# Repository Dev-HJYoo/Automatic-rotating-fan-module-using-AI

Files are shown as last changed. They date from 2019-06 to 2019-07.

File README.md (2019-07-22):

한글판의 경우 위의 웹사이트에서 확인할 수 있습니다.
#  Automatic rotating fan module using AI
> if you have a fan and install the module, you will use Automatic rotating fan.

**[[Presentation](Presentation)]**

 This project is the 2019 1st Semester Converged Capstone Design Project. 

 We learned AI in the first semester of 2019. we thought to use AI. And, we thought it would be all right if we made a fan to follow people in the hot summer. so, we made Automatic rotating fan module using object detection.

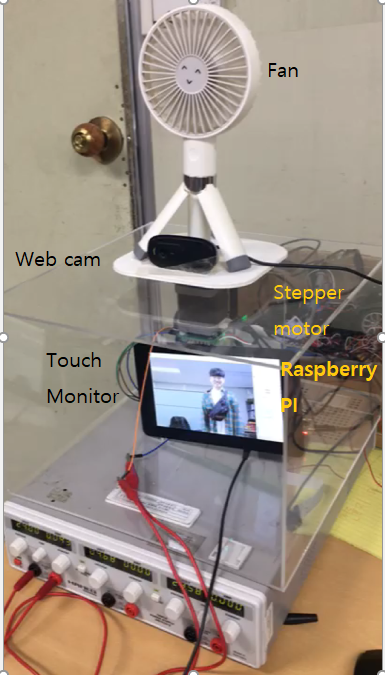
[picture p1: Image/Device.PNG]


Video Label (https://youtu.be/eMBiMkDRgPI?t=0s) 
Video Label (https://youtu.be/c7UqDB0MPdQ?t=0s) 

## Component

Device

- Raspberry pi 3B+
- Stepper Motor
- Touch Monitor
- Web cam
- PC

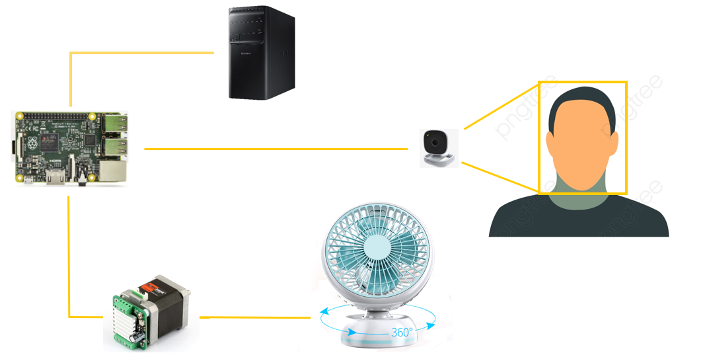
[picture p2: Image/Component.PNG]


## H/W

#### Outline Map
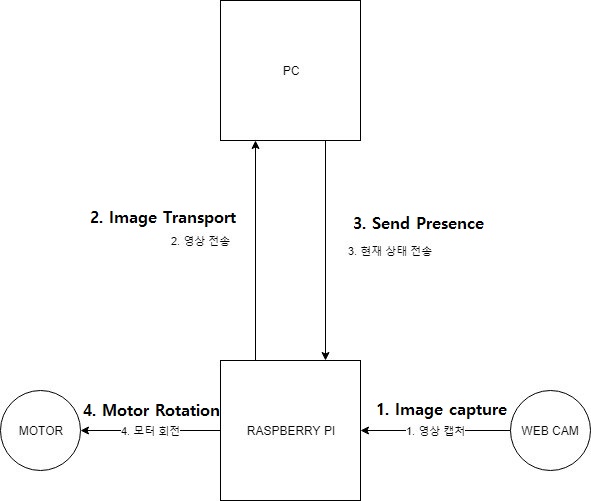
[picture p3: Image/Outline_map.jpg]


#### H/W Circuit

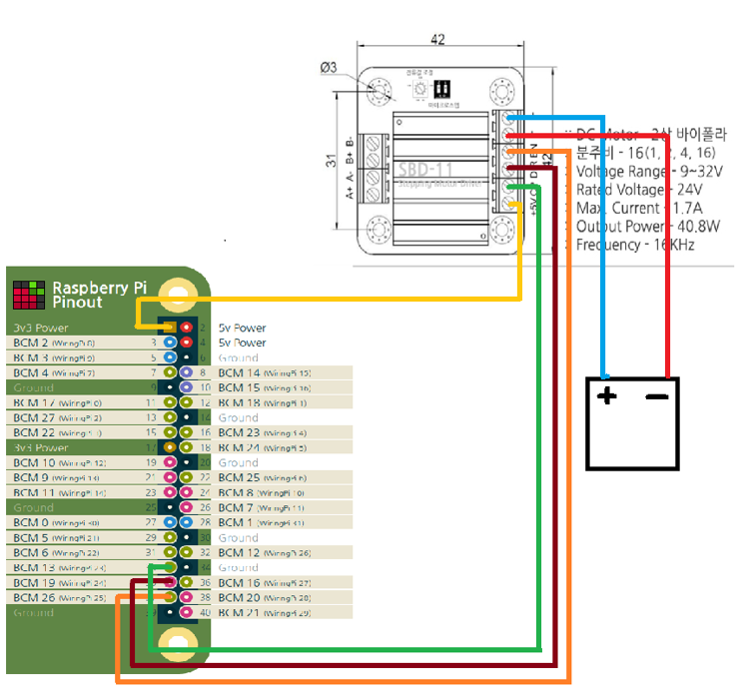
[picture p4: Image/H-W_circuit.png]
 

#### 3D Model
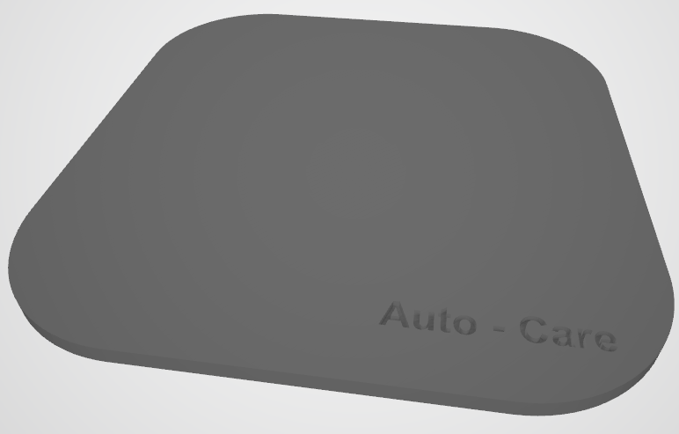
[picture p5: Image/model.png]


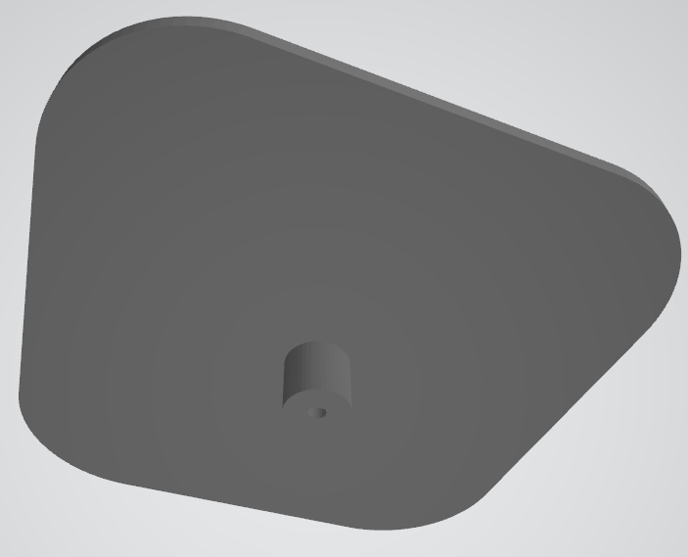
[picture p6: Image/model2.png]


## S/W

#### Object Detection

we used SSD-MobileNet-V1 model because we used Raspberry Pi( single board ). 

#### Algorithm

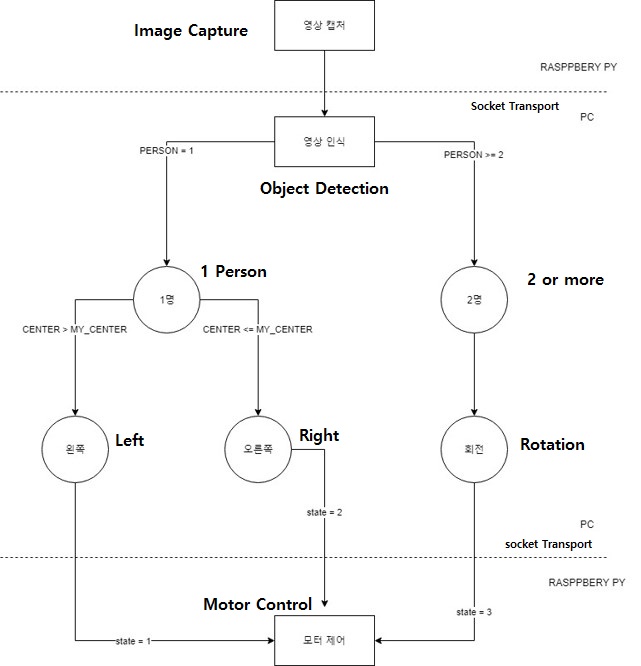
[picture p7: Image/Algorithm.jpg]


#### Socket Transport

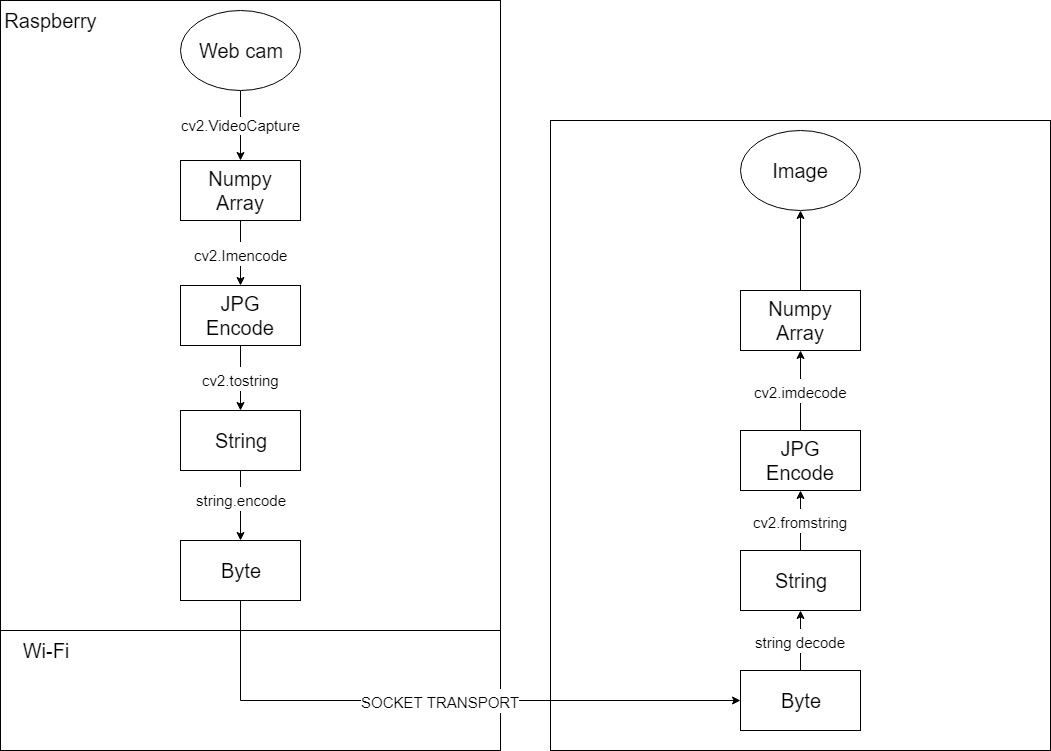
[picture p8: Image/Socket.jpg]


## Object Detection

#### Gather Data

using Capture/capture_from_webcam.py.

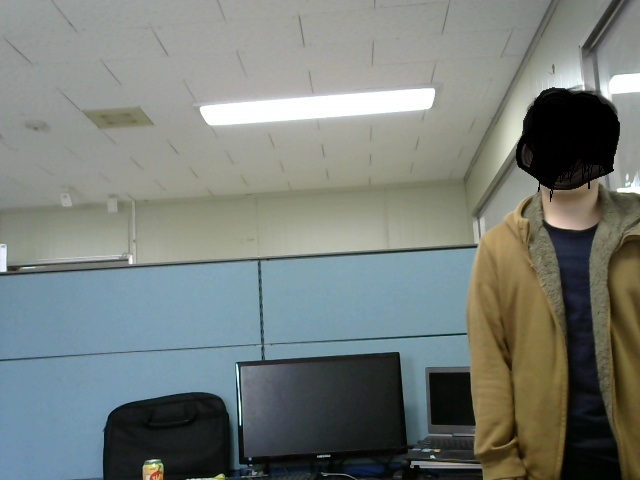
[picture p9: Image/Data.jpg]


#### Anotation

using [[3b.](https://github.com/EdjeElectronics/TensorFlow-Object-Detection-API-Tutorial-Train-Multiple-Objects-Windows-10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)]

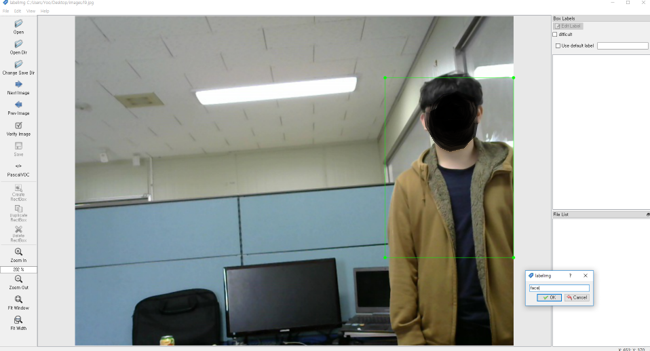
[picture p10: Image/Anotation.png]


#### Training

using [[4.Generate training data ~7. Export inference Graph](https://github.com/EdjeElectronics/TensorFlow-Object-Detection-API-Tutorial-Train-Multiple-Objects-Windows-10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)]

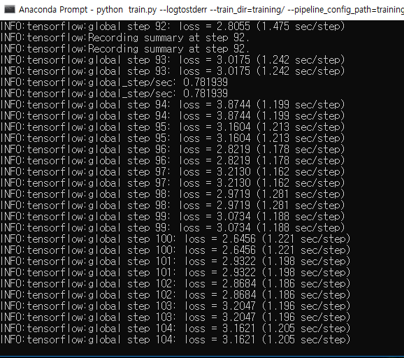
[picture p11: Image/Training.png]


Video Label (https://youtu.be/8JF9aYRYzJ4?t=0s) 

## How To Use?

See [[Object Detection](https://github.com/EdjeElectronics/TensorFlow-Object-Detection-API-Tutorial-Train-Multiple-Objects-Windows-10)] for preferences 

- Object_detection_webcam_server.py : Install PC
- Wifi.py : Installed Raspberry Pi

first, Run Object_detection_webcam_server.py.

second, Run Wifi.py.

## Presentation

### 

## Team members

- 유형준(Yoo Hyeong Jun) - Software Development [[Github](https://github.com/cocopambag)] [jhdf1234@naver.com]

- 김진호(Kim Jin Ho) - 3D Modeling [[Github](https://github.com/hiptoo1)] [hiptoo1@naver.com]

- 이대건  - Hardware Development [longchim@naver.com]

- 이정훈 - Software Development [[Github](https://github.com/foonia)] [ljh9032a@naver.com]

- 전주하 - Paperwork [[Github](https://github.com/LetsBee)] [hwe1123@naver.com]

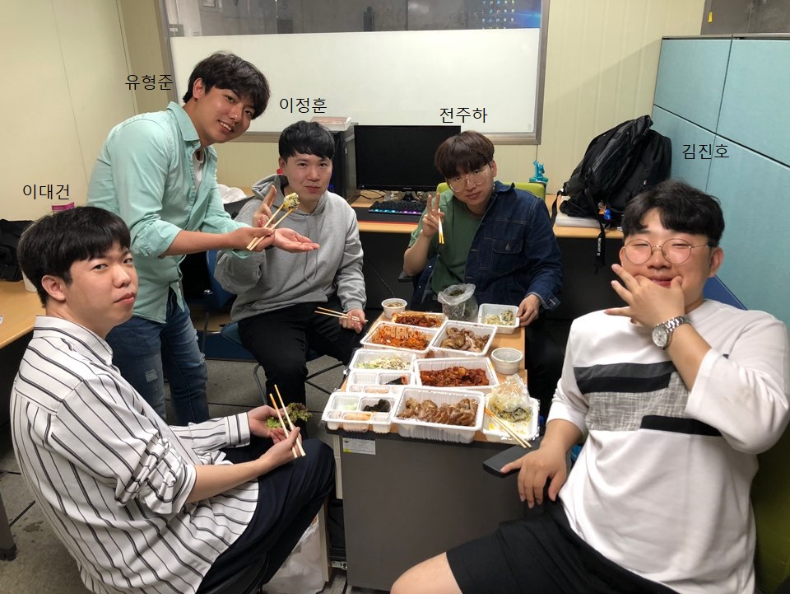
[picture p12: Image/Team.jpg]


## Reference Materials

- Object Detection - [[EdjeElectronics](https://github.com/EdjeElectronics/TensorFlow-Object-Detection-API-Tutorial-Train-Multiple-Objects-Windows-10)]
- Socket Transport - [[brownbears](https://brownbears.tistory.com/207)]
- Motor Control - [[Chandong83](https://m.blog.naver.com/chandong83/221156273595)]

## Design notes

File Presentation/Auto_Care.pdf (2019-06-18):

# AUTO FAN

p r e s e n t a t i o n

IT 공학부 | 20141166 이대건
IT 공학부 | 20131189 이정훈
IT 공학부 | 20141157 김진호
제어자동화공학부 | 20141164 유형준
IT 공학부 | 20141172 전주하

# 오토-판

## A U T O - C A R E ( 오토케어 )

3 page

목차

설계도

재료(MATERIAL)

진행 계획 및 현황

문제제시

진행표(SW/HW)

시연 영상

최종정산

Q&A

# 오토-판

2 page 설계도

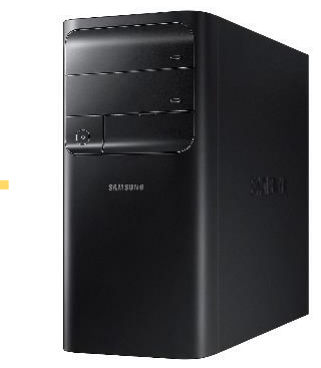
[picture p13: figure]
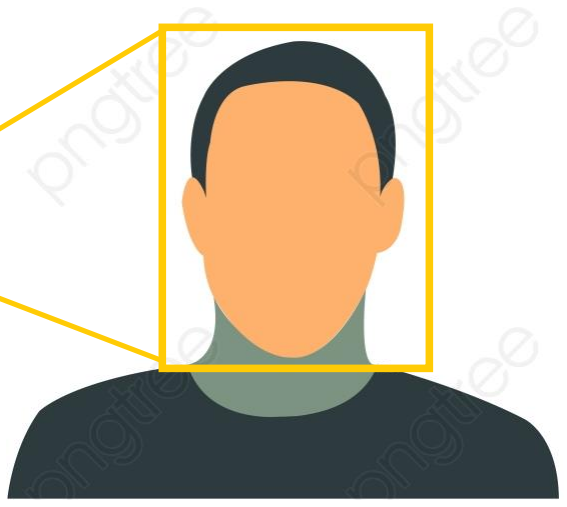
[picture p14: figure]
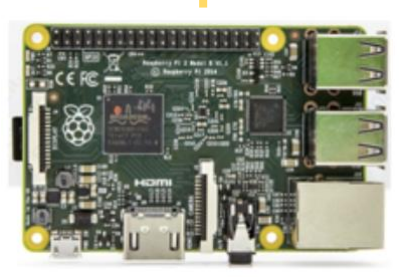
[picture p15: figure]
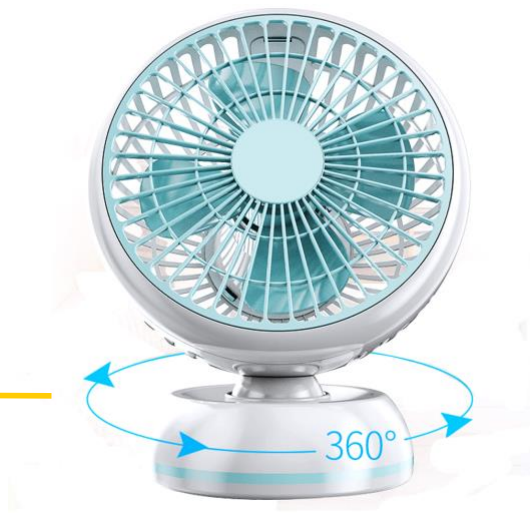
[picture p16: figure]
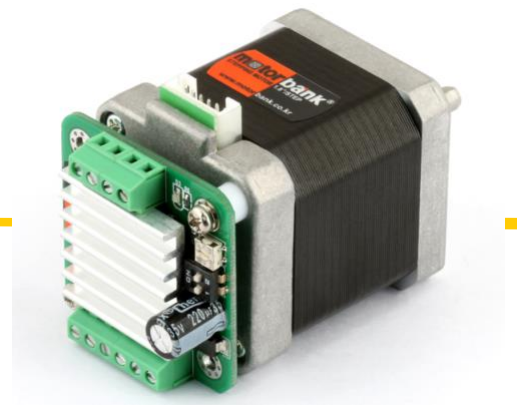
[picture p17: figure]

# 3 page MATERIAL

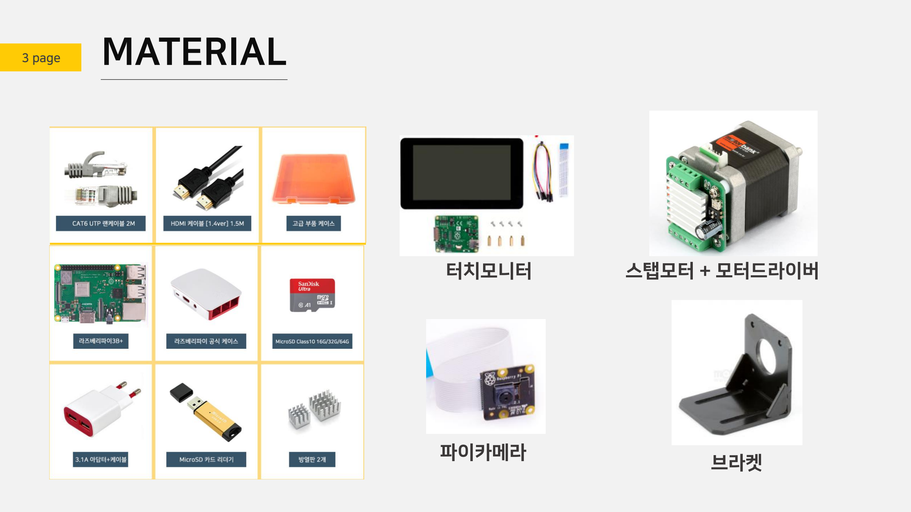
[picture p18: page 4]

터치모니터

파이카메라

스탭모터 + 모터드라이버

브라켓

# 진행 계획

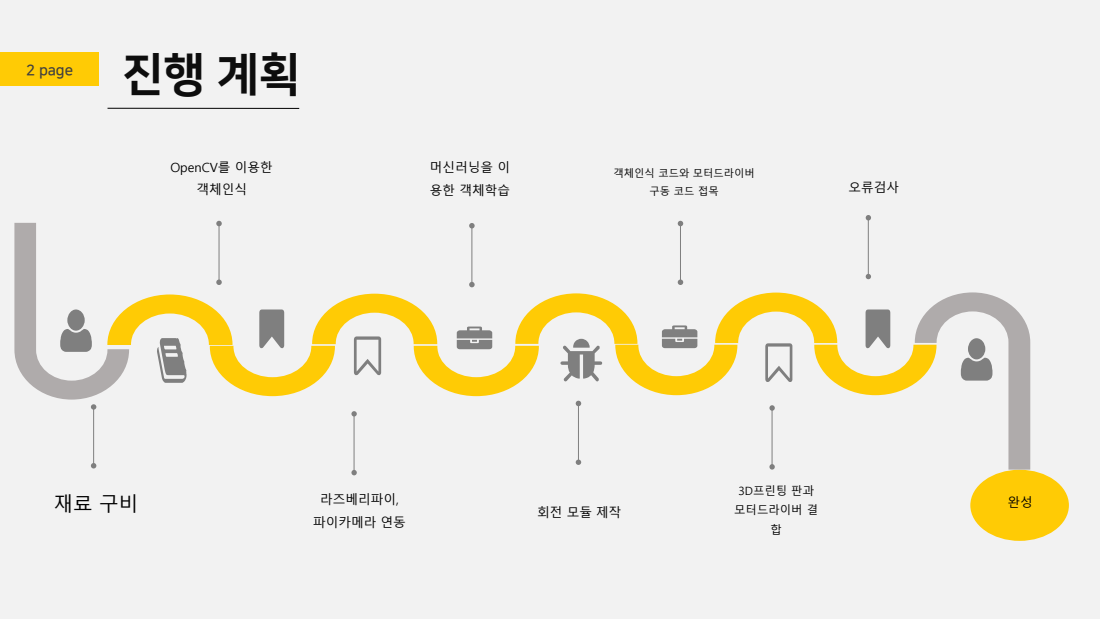
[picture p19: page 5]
2 page; 라즈베리파이,; 파이카메라 연동; 머신러닝을 이; 용한 객체학습; OpenCV를 이용한; 객체인식; 3D프린팅 판과; 모터드라이버 결; 오류검사

객체인식 코드와 모터드라이버

1 page | 문제 게시

문제점

해결방안

라즈베리파이 보드에서 사람인식을 진행할 경우
속도가 매우 느려서 모터의 운동이 낭비 현상 확인

PC와의 소켓통신 : 보드에서 캠을 통해 이미지를 받아오면 이를 와이파이를 통해 컴퓨터로 보내고
컴퓨터 측에서 사람을 인식하고 상태 정보를 보드 로 전송

## S/W 부분

1 page

## H/W 부분

문제점

해결방안

모터 컨트롤을 보드에서 할때 보드가 매우 뜨거워짐. 모터에서 보드를 통해 전력공급을 받는것이 문제

전압 전류 발생시켜 분리 공급 : 건전지 또는 전원 공급장치에서 받는것으로 해결

# 문제 게시

1 page | H/W 진행표
사진 | 내용

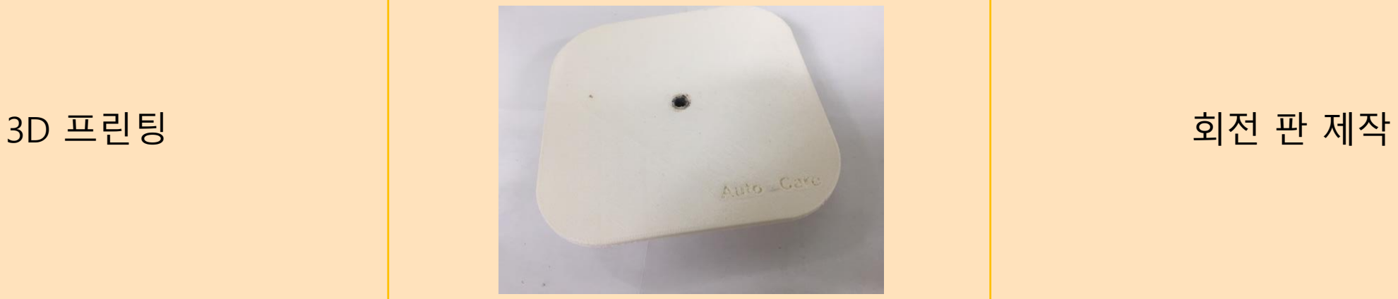
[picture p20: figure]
3D 프린팅
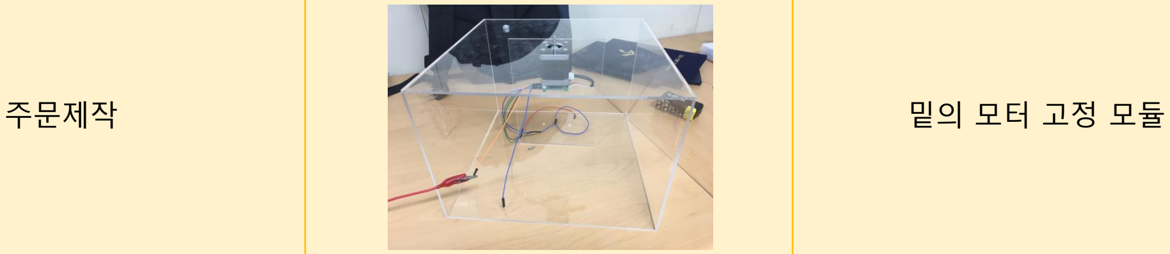
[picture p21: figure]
주문제작

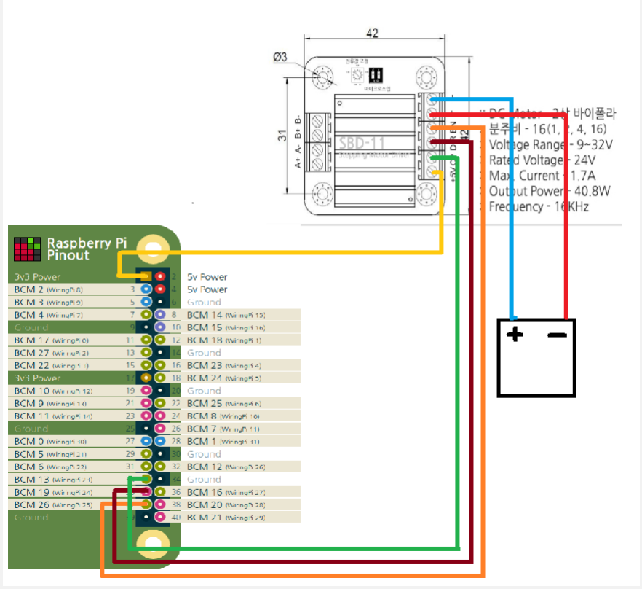
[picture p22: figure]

# 1 page H/W 진행표 회로 설계도

## 학습 부분

# S/W 진행표

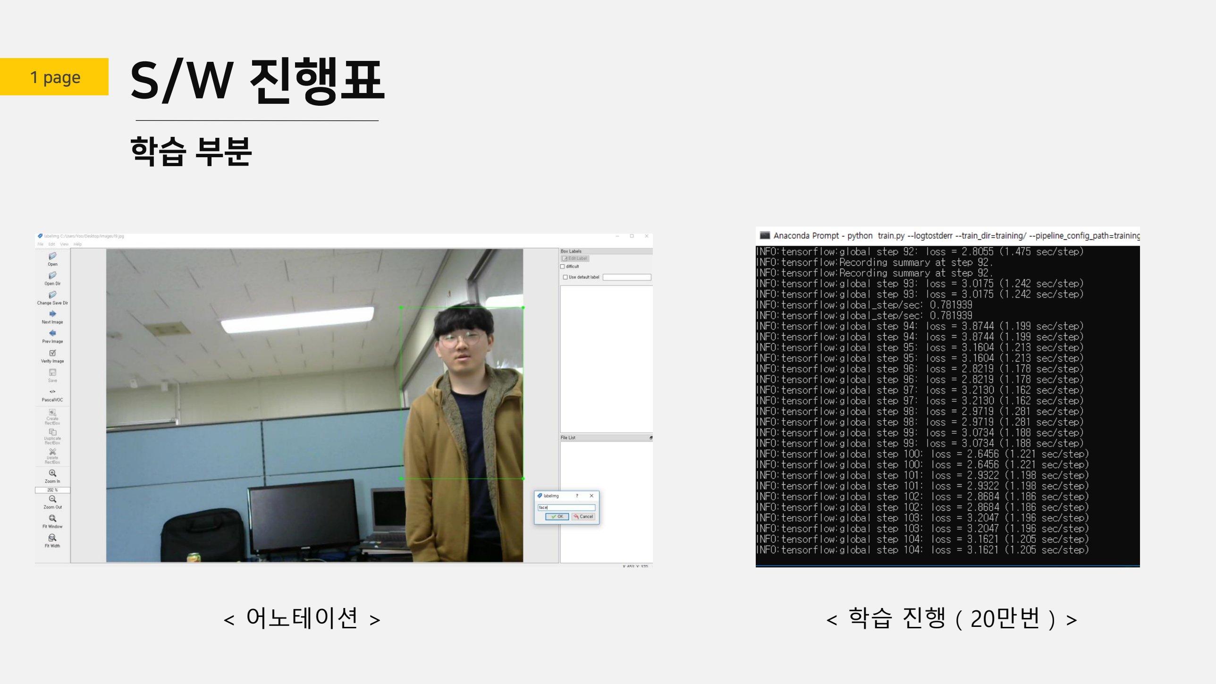
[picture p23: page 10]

1 page

< 어노테이션 > | < 학습 진행 ( 20만번 ) >

1 page

## 영상 처리 ( opencv 사용 )

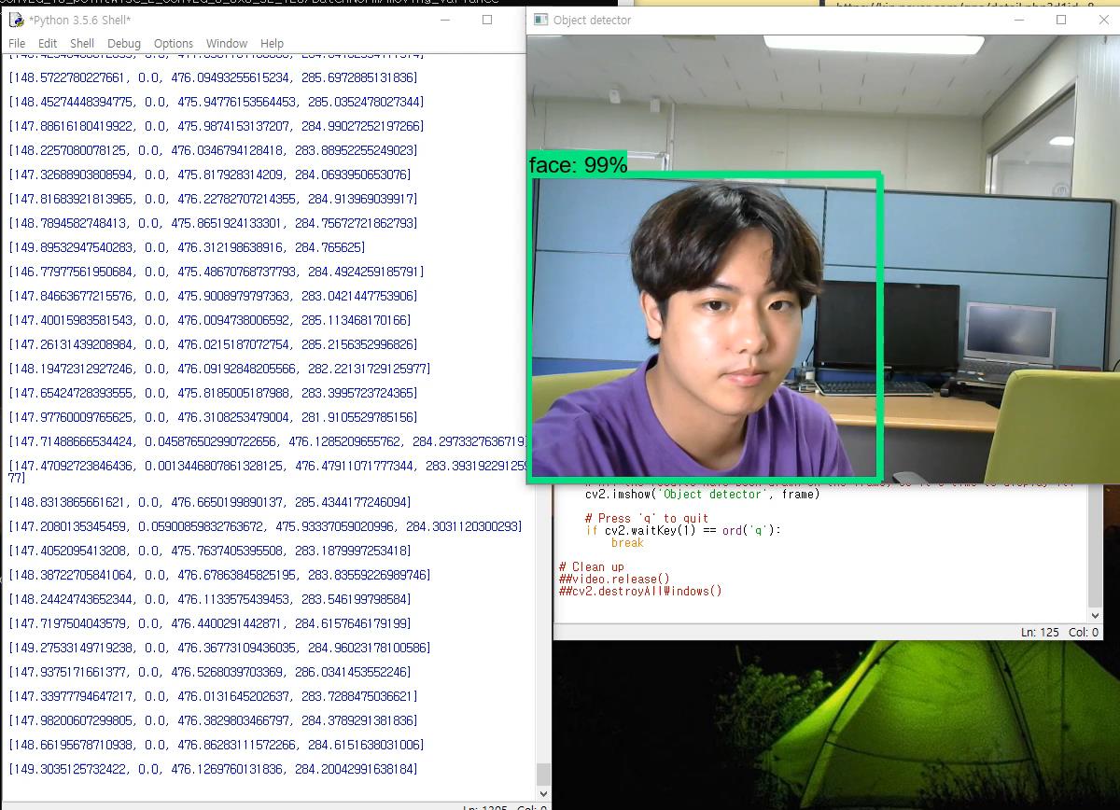
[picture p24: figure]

- 웹캡을 통해 영상 출력
- 사람 상체 인식 시 최저 꼭지점
과 최고 꼭지점 출력
- 화면 중앙점과 사각형 중앙점
을 비교해 촤측에 있는지 우측
에 있는지 인식

# S/W 진행표

1 page

## 소켓 통신 ( Socket 모듈 사용 )

# S/W 진행표

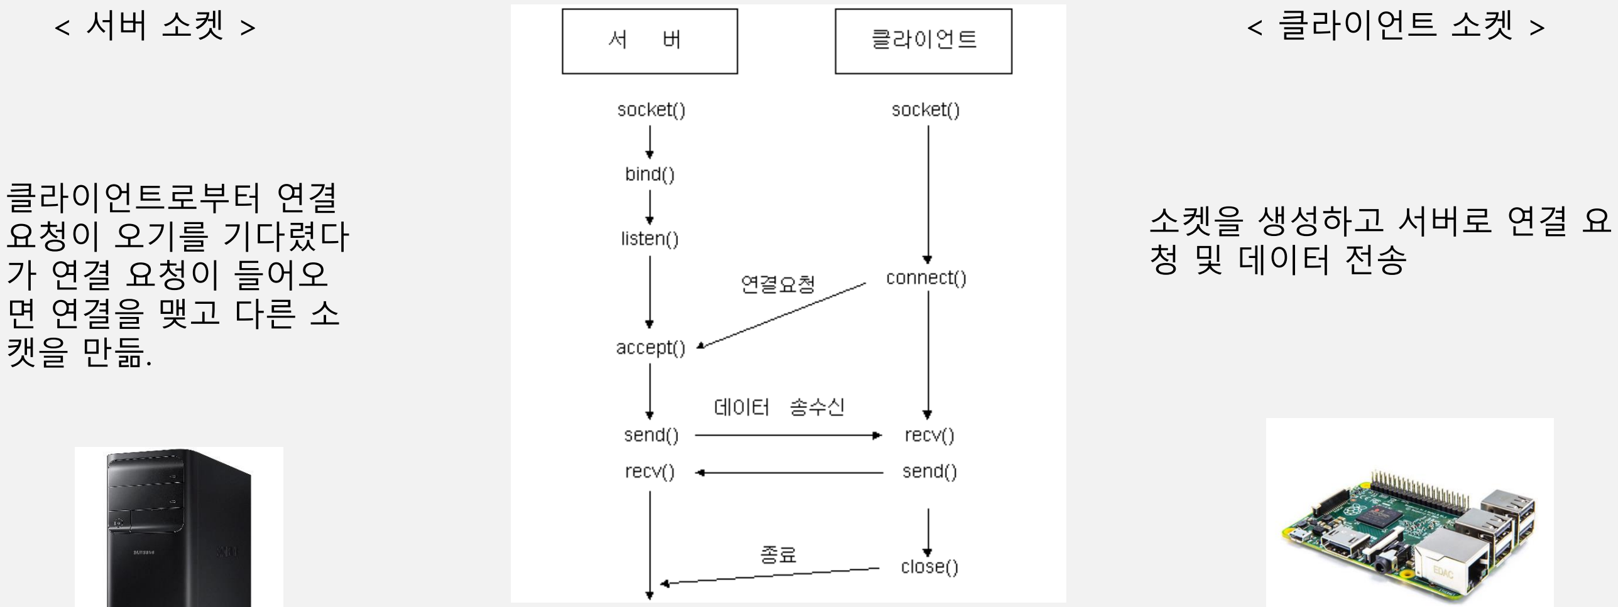
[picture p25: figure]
< 클라이언트 소켓 >; 클라이언트로부터 연결 요청이 오기를 기다렸다 가 연결 요청이 들어오 면 연결을 맺고 다른 소 캣을 만듦.; 소켓을 생성하고 서버로 연결 요 청 및 데이터 전송
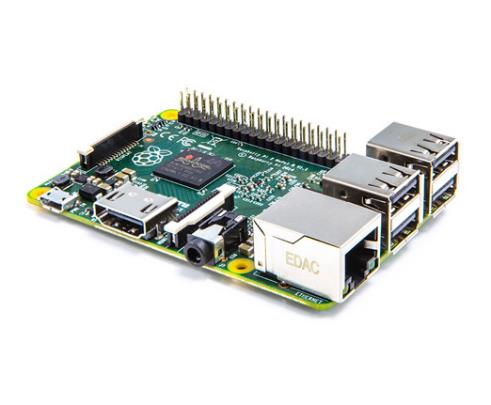
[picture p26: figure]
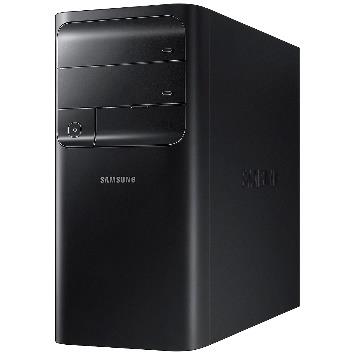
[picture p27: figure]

1 page

## 개요도

# S/W 진행표

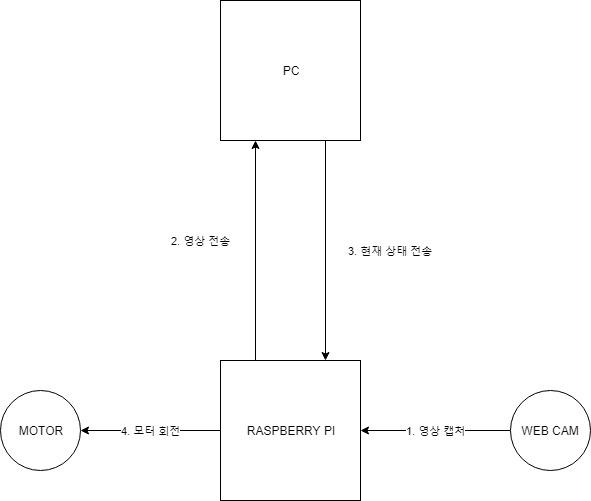
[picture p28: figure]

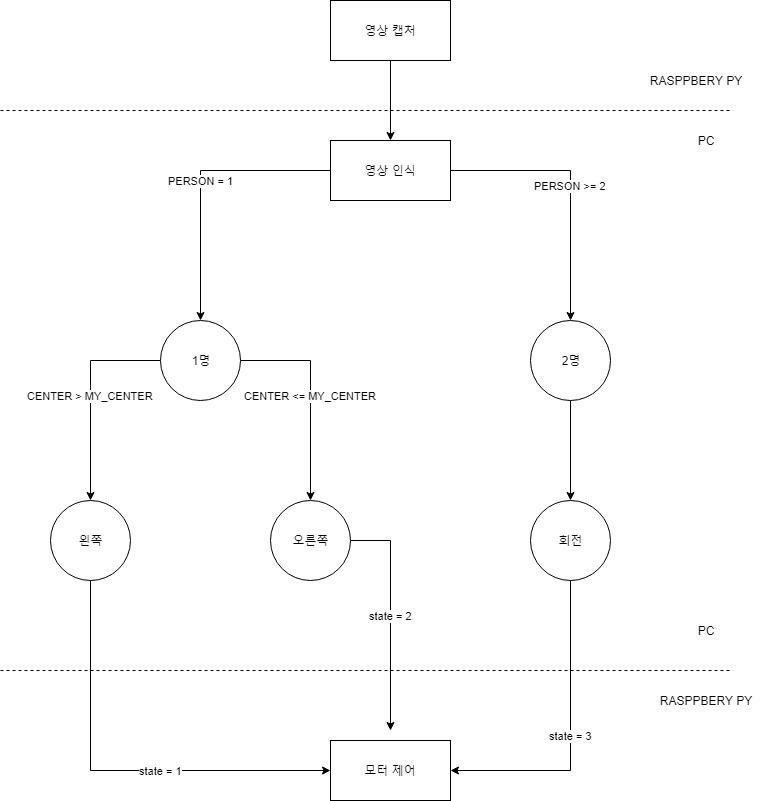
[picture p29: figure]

1 page

## 알고리즘

# S/W 진행표

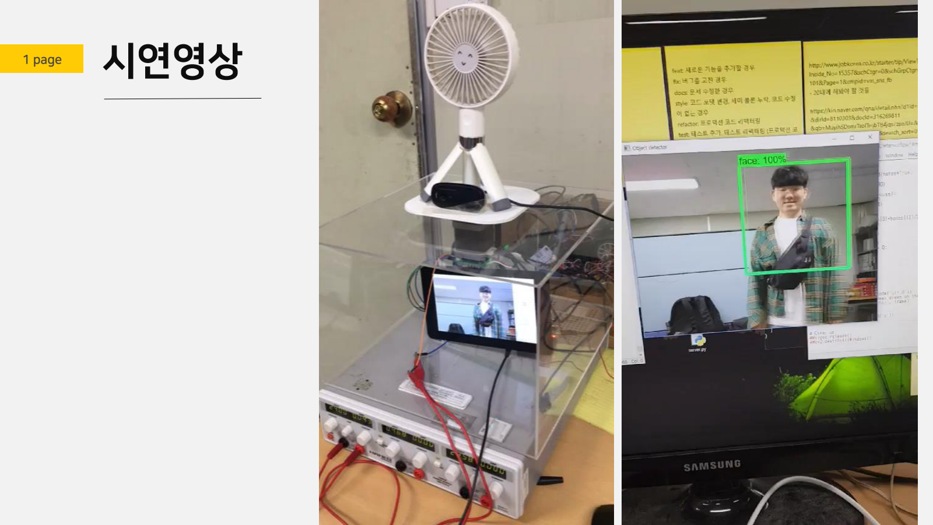
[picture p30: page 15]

1 page 시연영상

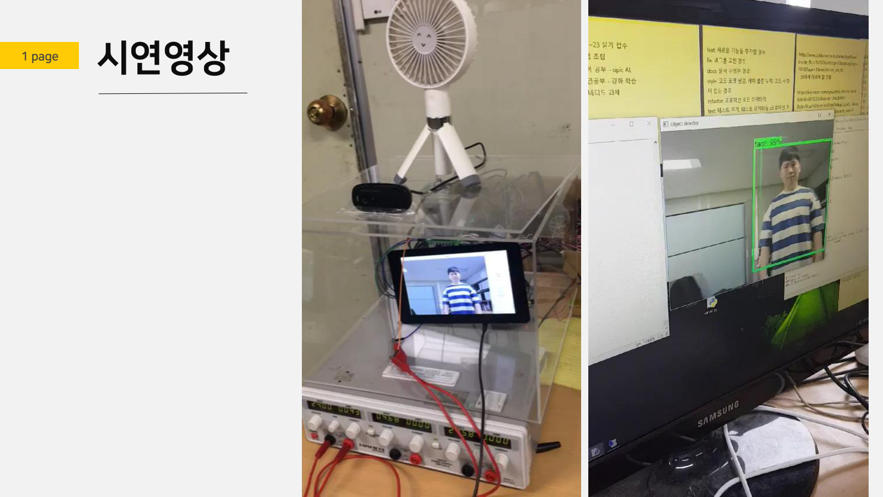
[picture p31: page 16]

1 page 시연영상

2 page | 최종장부
항 목 | 카드사용일자 | 정산내역 | 금회정산액 | 체크카드 /계좌이체 | 비고
재료비 | 19년 4월 12일 | 라즈베리파이3모델B+기본/스타터 키트 RaspberryPi3+Basic/StarterKit | 84,700원 | 체크카드
재료비 | 19년 4월 12일 | 라즈베리파이3모델B+기본/스타터 키트 RaspberryPi3+Basic/StarterKit | 79,200원 | 체크카드
재료비 | 19년 4월 12일 | 적외선카메라 V2 | 33,000원 | 체크카드
재료비 | 19년 4월 12일 | 7인치터치 LCD | 95,700원 | 체크카드
재료비 | 19년 4월 16일 | Nema 17 42각 드라이버 일체형 5.5Kg.cm 스테 핑모터 SBD-11-NK245-01AT 고성능 아두이노 | 49,500원 | 체크카드
재료비 | 18년 4월 16일 | 42각 스테핑모터 고정 브라켓 SMB-42M NEMA 17 시리즈 3D프린터 IoT 아두이노용 | 5,500원 | 체크카드
재료비 | 19년 5월 09일 | 핑모터 SBD-11-NK245-01AT 고성능 아두이노 Nema 17 42각 드라이버 일체형 5.5Kg.cm 스테 | 49,500원 | 체크카드 | 재품 파손으로 인한 재구매
재료비 | 19년 4월 16일 | 배송비 | 2,500원 | 체크카드
재료비 | 19년 5월 09일 | 배송비 | 2,500원 | 체크카드
합 계 | | | 402,100 원

2 page | 최종장부
항 목 | 카드사용일자 | 정산내역 | 금회정산액 | 체크카드 /계좌이체 | 비고
회의비 | 19년 4월17일 | 음식점명 :영도덮밥이랑 참석인원 : 5 명 | 44,500 원 | 체크카드
회의비 | 19년 5월13일 | 음식점명 : 족과의동침 참석인원 : 5 명 | 75,000 원 | 체크카드
회의비 | 19년 6월6일 | 음식점명 : (동삼)동근이숯불두마리치킨 참석인원 : 5 명 | 74,300 원 | 체크카드
회의비 | 19년 6월11일 | 음식점명 : 족과의동침 참석인원 : 5 명 | 75,000 원 | 체크카드
합 계 | | | 268,800 원

감사합니다.

부족하지만 예쁘게 봐주세요 : - )

Q&A

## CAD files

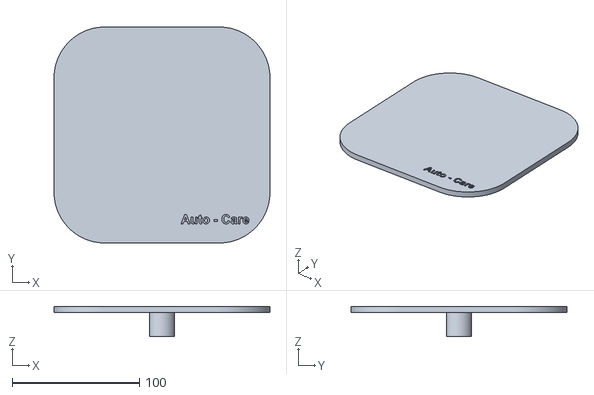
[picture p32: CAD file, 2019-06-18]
3D_Model/Final.stl
170.0 x 170.0 x 24.0

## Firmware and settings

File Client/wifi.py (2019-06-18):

######## Client ( Raspberry Pi ) Code #########
#
# Author: Yoo Hyeong Jun
# Date: 6/18/19
# Description: 
# This program uses Motor code and Socket transport code
# It captures image from webcam.
# it sends image to server via socket transport.
# It receive state information from server via socket transport.
# It use convert image to jpg.
# It use convert numpy array to string.
# Using Socket Transport
# Transport Presentence ( Left - 1, Right - 2, Rotation - 3 )

## Some of the code is copied from Motor Control at
## https://m.blog.naver.com/chandong83/221156273595

## Some of the code is copied from Socket Transport at
## https://brownbears.tistory.com/207

## but I changed it to make it more understandable and usable to me




# import 
import cv2
import socket
import numpy as np
import RPi.GPIO as GPIO
from time import sleep
import threading


##### Motor
STOP  = 0
FORWARD  = 1
BACKWARD = 2
# motor channel
CH1 = 0
CH2 = 1
# PIN io set
OUTPUT = 1
INPUT = 0
# PIN set
HIGH = 1
LOW = 0
# pin define
#PWM PIN
ENA = 26  #37 pin
#GPIO PIN
IN1 = 19  #35 pin
IN2 = 13  #33 pin

# pin set func
def setPinConfig(EN, INA, INB):        
    GPIO.setup(EN, GPIO.OUT)
    GPIO.setup(INA, GPIO.OUT)
    GPIO.setup(INB, GPIO.OUT)
    # 100khz PWM run 
    pwm = GPIO.PWM(EN, 1) 
    # PWM stop for run   
    pwm.start(0) 
    return pwm

# motor control func
def setMotorContorl(pwm, IN1, IN2, speed, stat):
    # motor speed control PWM
    pwm.ChangeDutyCycle(speed)  
    count = 0
    if stat == FORWARD:
        GPIO.output(IN1, 0)
        while True: 
            GPIO.output(IN2, 0) 

            GPIO.output(IN2, 1)
            #setMotor(CH1, 50, FORWARD)
            count+=1
            if count==500:
                break
    elif stat == BACKWARD:
        GPIO.output(IN1, 1)
        while True: 
            GPIO.output(IN2, 0) 

            GPIO.output(IN2, 1)
            #setMotor(CH1, 50, FORWARD)
            count+=1
            if count==500:
                break
            
# rapping func for run easy
def setMotor(ch, speed, stat):
    if ch == CH1:
        #pwmA set get pwm handdle
        setMotorContorl(pwmA, IN1, IN2, speed, stat)  

# Thread Func	
def execute():
    # state is global
    global state

    # Motor init
    count = 0
    GPIO.setmode(GPIO.BCM)
    pwmA = setPinConfig(ENA, IN1, IN2)
    pwmA.ChangeDutyCycle(50)

    # Motor Control
    while True:
        print(state)

        # Left
        if state == 1:
            GPIO.output(IN1, 0)
            while True: 
                GPIO.output(IN2, 0) 
                sleep(0.01)
                GPIO.output(IN2, 1)
                #setMotor(CH1, 50, FORWARD)
                count+=1
                if count==2:
                    count = 0
                    break

        # Right
        elif state == 2:
            GPIO.output(IN1, 1)
            while True: 
                GPIO.output(IN2, 0) 
                sleep(0.01)
                GPIO.output(IN2, 1)
                #setMotor(CH1, 50, FORWARD)
                count+=1
                if count==2:
                    count = 0
                    break
                
        # Rotation
        else: 
            while True: 
                GPIO.output(IN2, 0) 
                sleep(0.01)
                GPIO.output(IN2, 1)
                #setMotor(CH1, 50, FORWARD)
                count+=1
                if count==2:
                    count = 0
                    break

            

# Receive Func
def recvall(sock, count):
    # Byte String
    buf = b''
    while count:
        newbuf = sock.recv(count)
        if not newbuf: return None
        buf += newbuf
        count -= len(newbuf)
    return buf

s = socket.socket(socket.AF_INET, socket.SOCK_STREAM)

s.connect(('PC_IP', 8485))

cam = cv2.VideoCapture(0)


d = socket.socket(socket.AF_INET, socket.SOCK_STREAM)
d.bind(('Raspberry_IP',8486))
d.listen(10)
donn, addr = d.accept()

# encode parameter
encode_param = [int(cv2.IMWRITE_JPEG_QUALITY), 90]

my_thread = threading.Thread(target = execute) # Define Thread
my_thread.start()     # Start Thread

# state = 3
state = 3

while True:

	# Capture image from webcam
	ret, frame = cam.read()

	# view webcam
	cv2.imshow('frame', frame)
	if cv2.waitKey(1) == ord('q'):
	    break

	# convert to jpg
	result, frame = cv2.imencode('.jpg', frame, encode_param)

	# numpy array of image
	data = np.array(frame)

	# convert string
	stringData = data.tostring()

	# Send 16byte( string length ) and string data
	s.sendall((str(len(stringData))).encode().ljust(16) + stringData)

        # receive state string
	rev = int(recvall(donn,1).decode('utf-8'))
	
	state = rev
				
	
cam.release()
